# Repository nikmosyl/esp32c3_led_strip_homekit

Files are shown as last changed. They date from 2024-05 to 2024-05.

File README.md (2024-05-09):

# ESP32 LED Strip WS2812 HomeKit
[ru](https://github.com/nikmosyl/esp32c3_led_strip_homekit/blob/main/Readme/README-ru.md)

Hardware and Frimware for an addressable LED strip controller based on ESP32-C3

## Hardware

<kbd>
  
</kbd>

<kbd>
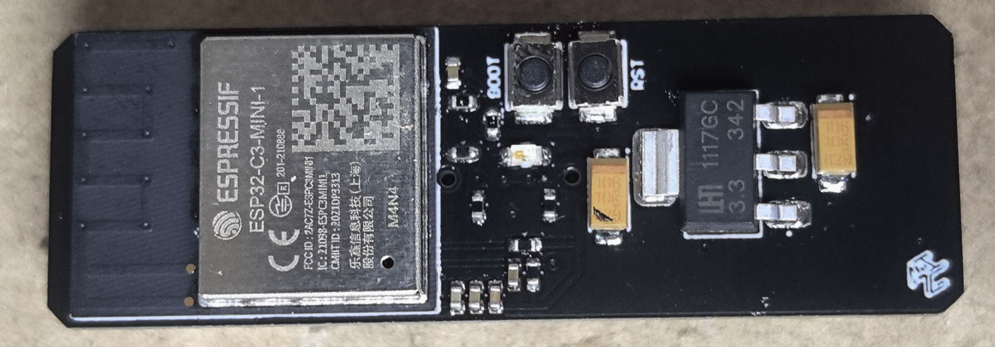
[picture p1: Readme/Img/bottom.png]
  
</kbd>

[altium 365 web preview](https://365.altium.com/files/029D88F9-241C-48A4-977B-14C8D9AD6741?variant=[No+Variations])

You can order it [here](https://www.pcbway.com/project/shareproject/ws2812esp32_3_v1_792a8e86.html)

On board:
- [Input connector](https://www.digikey.com/en/products/detail/amphenol-cs-commercial-products/FLTS22WR00/20422799) for power supply of the controller and LED strip (LED strip WS2812 or similar with +5V power supply)
- [Output connector](https://www.digikey.com/en/products/detail/amphenol-cs-commercial-products/FLTS32WR00/20426575) for power supply and control signal for addressable LED strip
- USB type C for programming ESP32-C3 controller

## Frimware
Based on Espressif [SDK](https://github.com/espressif/esp-homekit-sdk)

General installation steps using sources:

### 1. Install [ESP-IDF](https://docs.espressif.com/projects/esp-idf/en/stable/esp32c3/get-started/linux-macos-setup.html)
Preferred version v5.2.1

Preferred installation location is at the root of your home directory ~/

### 2. Install [esp-homekit-sdk](https://github.com/espressif/esp-homekit-sdk)
Preferred installation location is at the root of your home directory ~/

### 3. Download the repository with the project
```bash
cd ~/
git clone https://github.com/nikmosyl/esp32c3_led_strip_homekit.git
```

### 4. Configure HomeKit device and LED strip settings
File esp32c3_led_strip_homekit/frimware/lightbulb/main/app_main.c line 162:
```C
hap_acc_cfg_t cfg = {
    .name = "Esp-Light",                  //device name displayed in the Home app
    .manufacturer = "Espressif",          
    .model = "EspLight01",
    .serial_num = "202405030213",         //when using multiple devices, the number must be unique
    .fw_rev = "0.1.0",
    .hw_rev = "1.0",
    .pv = "1.1.0",
    .identify_routine = light_identify,
    .cid = HAP_CID_LIGHTING,
};
```
File frimware/lightbulb/main/Libs/internal_led/internal_led.c line 10:
```C
#define BLUE_LED 5    //GPIO number with debug LED on the board used
```
File frimware/lightbulb/main/Libs/led_strip/led_strip_control.c line 14:
```C
#define FLOW 30               //delay in milliseconds between switching on adjacent LEDs on the strip
#define LED_STRIP_GPIO 7      //GPIO number to which the DI pin of the LED strip is connected
#define LED_COUNT 10          //number of LEDs on LED strip
```

### 5. Set environment variables (can be skipped when installing idf and sdk in preferred paths)
You can either register temporary environment variables (specify the path to esp-homekit-sdk):
```bash
export HOMEKIT_PATH=~/esp/esp-homekit-sdk 
```
Or edit the file firmware/lightbulb/CMakeLists.txt line 11:
```CMake
set(HOMEKIT_PATH ~/esp/esp-homekit-sdk)
```
Instead of ~/esp/esp-homekit-sdk, specify your path to the esp-homekit-sdk directory

### 6. Set Wi-Fi password
You can either leave everything as it is, and then upon first launch, a QR code will be displayed in the console for connecting via [Espressif Provisioning Apps](https://docs.espressif.com/projects/esp-idf/en/latest/esp32/api-reference/provisioning/provisioning.html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) 

Or hardcode the Wi-Fi password into the controller:
```bash
cd ~/esp32c3_led_strip_homekit/frimware/lightbulb
. ~/esp/esp-idf/export.sh
```
Here the esp32c3 microcontroller to be flashed is selected as on the board from the Hardware section, you must specify the one that is on the board to be flashed
```bash
idf.py set-target esp32c3
idf.py menuconfig
```

In the section _**App Wi-Fi** -> **Source of Wi-Fi Credentials**_ you need to check the box for **Use Hardcoded**

In the fields that appear, you must enter the name and password of the access point

Press S (Save) and Enter after that

### 7. Flash the board
To do this, you need to connect the board to the PC, make sure that it is visible in the list of devices and there is access to its serial port;

Switch the board to firmware mode (on the board from the Hardware section this is done by pressing the RST button while holding down the BOOT button);

Build firmware:
```bash
idf.py build
```
Upload firmware to the board:
```bash
idf.py flash
```

### 8. After the firmware
Reboot the board
Wait until it connects to Wi-Fi and appears in the menu for adding new HomeKit devices (on iPhone, _**Home** app -> **+** -> **Other options** -> **select device**_ , code 11122333)

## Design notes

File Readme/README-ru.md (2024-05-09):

# ESP32 LED Strip WS2812 HomeKit
[en](https://github.com/nikmosyl/esp32c3_led_strip_homekit/blob/main/README.md)

Hardware и Frimware для контроллера адресной светодиодной ленты на базе ESP32-C3

## Hardware

<kbd>
  
</kbd>

<kbd>
  
</kbd>

[веб превью altium 365](https://365.altium.com/files/029D88F9-241C-48A4-977B-14C8D9AD6741?variant=[No+Variations])

Заказать можно [тут](https://www.pcbway.com/project/shareproject/ws2812esp32_3_v1_792a8e86.html)

На плате:
- [Входной разъём](https://www.digikey.com/en/products/detail/amphenol-cs-commercial-products/FLTS22WR00/20422799) для питание контролера и светодиодной ленты (светодиодная лента WS2812 или аналогичная с питанием +5V)
- [Выходной разъём](https://www.digikey.com/en/products/detail/amphenol-cs-commercial-products/FLTS32WR00/20426575) для питания и управляющего сигнала адресной светодиодной лентой
- USB type C для программирования контроллера ESP32-C3

## Frimware
Основано на [SDK](https://github.com/espressif/esp-homekit-sdk) от Espressif 

Общие шаги по установке c использованием исходников:

### 1. Установить [ESP-IDF](https://docs.espressif.com/projects/esp-idf/en/stable/esp32c3/get-started/linux-macos-setup.html)
Предпочительная версия v5.2.1

Предпочтительное место установки в корень домашней директории ~/

### 2. Установить [esp-homekit-sdk](https://github.com/espressif/esp-homekit-sdk)
Предпочтительное место установки в корень домашней директории ~/

### 3. Скачать репозиторий с проектом
```bash
cd ~/
git clone https://github.com/nikmosyl/esp32c3_led_strip_homekit.git
```

### 4. Настроить параметры HomeKit устройства и светодиодной ленты
Файл esp32c3_led_strip_homekit/frimware/lightbulb/main/app_main.c строка 162:
```C
hap_acc_cfg_t cfg = {
    .name = "Esp-Light",                  //отображаемое в приложении Дом название устройства
    .manufacturer = "Espressif",          
    .model = "EspLight01",
    .serial_num = "202405030213",         //при использовании нескольких устройств номер должен быть уникальным
    .fw_rev = "0.1.0",
    .hw_rev = "1.0",
    .pv = "1.1.0",
    .identify_routine = light_identify,
    .cid = HAP_CID_LIGHTING,
};
```
Файл frimware/lightbulb/main/Libs/internal_led/internal_led.c строка 10:
```C
#define BLUE_LED 5    //номер GPIO с отладочным свтодиодом на используемой плате
```
Файл frimware/lightbulb/main/Libs/led_strip/led_strip_control.c строка 14:
```C
#define FLOW 30               //задержка в милесекундах между включениями соседних сетодиодов на ленте
#define LED_STRIP_GPIO 7      //номер GPIO к которому подлючен контакт DI светодиодной ленты
#define LED_COUNT 10          //количество светодиодов на светодиодной ленте
```

### 5. Прописать переменные окружения (можно пропустить при установке idf и sdk по предпочтительным путям)
Можно либо прописать временные переменные окружения (указать путь до esp-homekit-sdk):
```bash
export HOMEKIT_PATH=~/esp/esp-homekit-sdk 
```
Либо отредоктировать файл frimware/lightbulb/CMakeLists.txt строка 11:
```CMake
set(HOMEKIT_PATH ~/esp/esp-homekit-sdk)
```
вместо ~/esp/esp-homekit-sdk указать свой путь к каталогу esp-homekit-sdk

### 6. Установить пароль Wi-Fi
Можно либо оставить всё как есть и тогда при первом запуске в консоль выведется QR код для подключения через [Espressif Provisioning Apps](https://docs.espressif.com/projects/esp-idf/en/latest/esp32/api-reference/provisioning/provisioning.html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) 

Либо зашить пароль от Wi-Fi в контроллер жёстко:
```bash
cd ~/esp32c3_led_strip_homekit/frimware/lightbulb
. ~/esp/esp-idf/export.sh
```
Здесь выбран прошиваемый микроконтроллер esp32c3 как на плате из раздела Hardware, необходимо указать тот, который стоит на прошиваемой плате
```bash
idf.py set-target esp32c3
idf.py menuconfig
```

В разделе _**App Wi-Fi** -> **Source of Wi-Fi Credentials**_ нужно установить галочку на **Use Hardcoded**

В появившиеся поля необходимо ввести имя и пароль точки доступа

Нажать S (Save) и Enter после этого

### 7. Прошить плату
Для этого нужно подключить плату к ПК, убедиться, что она видна в списке устройств и к её последовательному порту есть доступ;

Перевести плату в режим прошивки (на плате из раздела Hardware это делается путём нажатия кнопки RST при удерживании кнопки BOOT);

Собрать прошивку:
```bash
idf.py build
```
Загрузить прошивку на плату:
```bash
idf.py flash
```

### 8. После прошивки
Перезагрузить плату
Дождаться пока она подключится к Wi-Fi и отобразится в меню добавления новых устройств HomeKit (на iPhone приложение _**Дом** -> **+** -> **Другие параметры** -> **выберете устройство**_, код 11122333)

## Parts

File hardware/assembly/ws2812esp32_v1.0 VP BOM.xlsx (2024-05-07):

Designator | Quantity | Manufacture | Part Number | Description | Case | Case Type
C1, C2, C10 | 3 | Murata | GRM155R71H104KE14D | CAP CER 0.1UF 50V X7R 0402 | 0402 | SMD
C3, C7 | 2 | Kemet | T491A106K010AT | CAP TANT 10UF 10% 10V 1206 | Molded A | SMD
C4, C6 | 2 | Murata | GRM1555C1H150JA01D | CAP CER 15PF 50V C0G/NP0 0402 | 0402 | SMD
C5, C8, C11 | 3 | Murata | GRM155R61E105KA12D | CAP CER 1UF 25V X5R 0402 | 0402 | SMD
C9 | 1 | Murata | GRM155R71E103KA01D | CAP CER 10000PF 25V X7R 0402 | 0402 | SMD
DA1 | 1 | Taejin | LM1117GS-3.3 | IC REG LINEAR 3.3V 1A SOT223-3 | SOT-223 | SMD
DD1 | 1 | TI | SN74LVC1T45DCK | IC TRANSLTR BIDIRECTIONAL SC70-6 | SC70 DCK | SMD
DD2 | 1 | Espressif | ESP32-C3-MINI-1 | RF TXRX MODULE BT PCB TRACE SMD | SMD Module 13.2 x 12.5 x 2.4 | SMD
HL1 | 1 | Kingbright | APT1608QBC/D | LED 0603 Blue | 0603 | SMD
K1, K2 | 2 | Omron | B3U-1000P-B | SWITCH TACTILE SPST-NO 0.05A 12V | 3.0 x 2.5 x 1.85 | SMD
R1, R2, R7, R8 | 4 | Yageo | RC0402FR-0710KL | RES 10K OHM 1/16W 1% 0402 SMD | 0402 | SMD
R3, R4 | 2 | Yageo | RC0402FR-075K1L | RES 5.1K OHM 1/16W 1% 0402 SMD | 0402 | SMD
R5, R6 | 2 | Yageo | RC0402FR-0722RL | RES 22 OHM 1/16W 1% 0402 SMD | 0402 | SMD
R9 | 1 | Yageo | RC0402FR-071KL | RES 1K OHM 1/16W 1% 0402 SMD | 0402 | SMD
VD1 | 1 | MDD | DSK14 | DIODE SCHOTTKY 40V 1A | SOD-123FL | SMD
XS1 | 1 | Amphenol | FLTS22WR00 | SMD TERMINAL BLOCK 2 PIN | 7.9 x 13.1 x 4.6 | SMD
XS2 | 1 | GCT | USB4110-GF-A | CONN RCP USB2.0 TYP C 24P SMD RA | USB2.0 TYP C 24P SMD RA | SMD
XS3 | 1 | Amphenol | FLTS32WR00 | SMD TERMINAL BLOCK 3 PIN | 11.9 x 13.1 x 4.6 | SMD

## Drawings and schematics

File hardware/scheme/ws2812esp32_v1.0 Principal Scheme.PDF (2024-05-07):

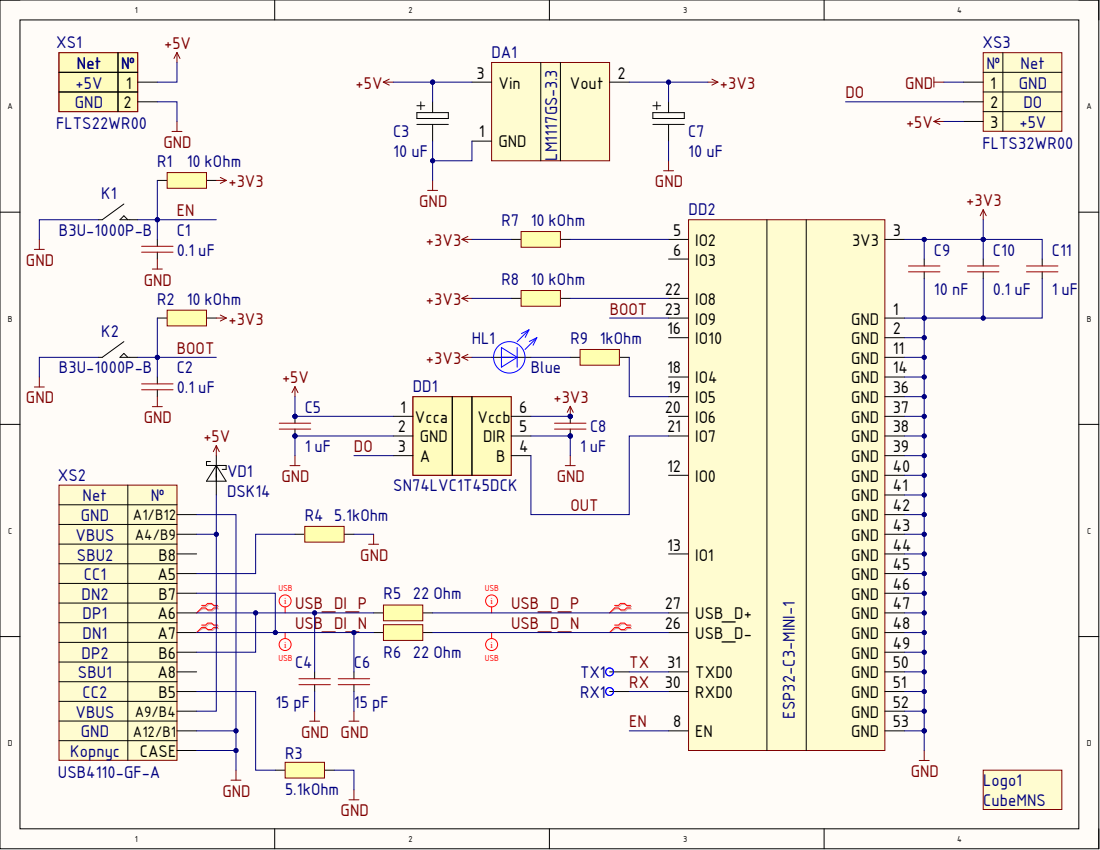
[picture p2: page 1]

Net | №
GND | A1/B12
VBUS | A4/B9
SBU2 | B8
CC1 | A5
DN2 | B7
DP1 | A6
DN1 | A7
DP2 | B6
SBU1 | A8
CC2 | B5
VBUS | A9/B4
GND | A12/B1
Корпус | CASE

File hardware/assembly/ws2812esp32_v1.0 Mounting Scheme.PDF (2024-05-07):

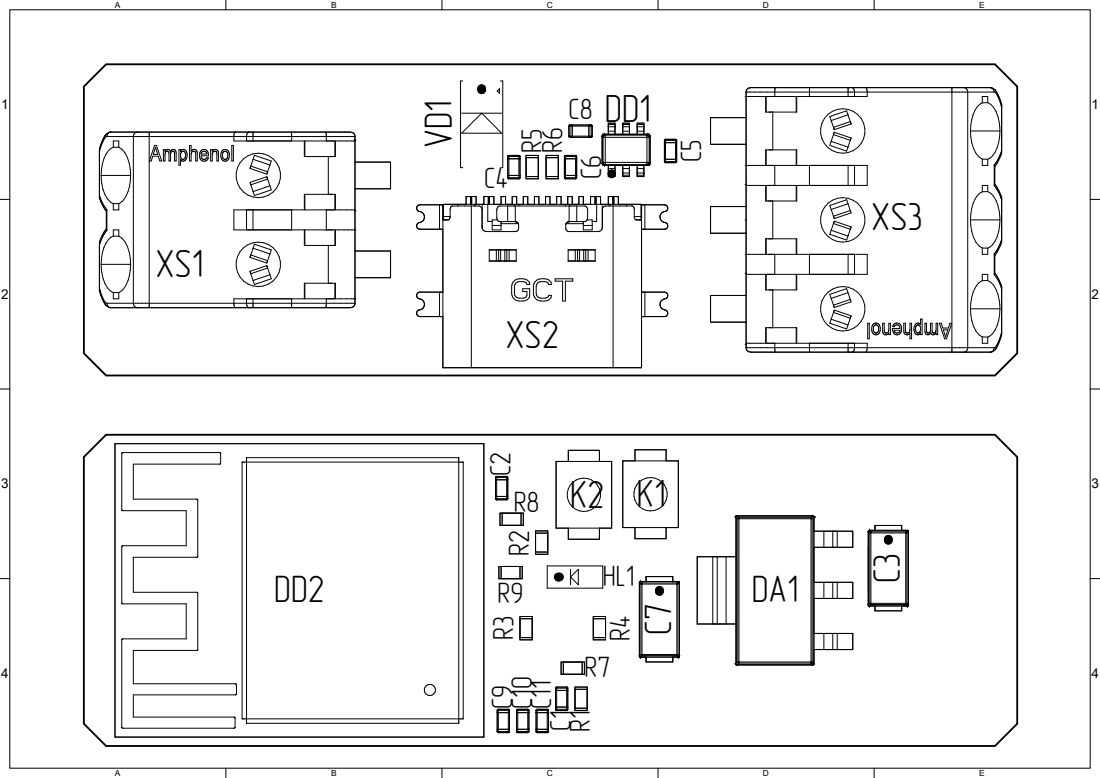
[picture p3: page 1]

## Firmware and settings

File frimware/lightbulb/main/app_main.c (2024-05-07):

/*
 * ESPRESSIF MIT License
 *
 * Copyright (c) 2018 <ESPRESSIF SYSTEMS (SHANGHAI) PTE LTD>
 *
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
 */

/* HomeKit Lightbulb for esp32c3 custom board
*/

#include <stdio.h>
#include <string.h>
#include <freertos/FreeRTOS.h>
#include <freertos/task.h>
#include <esp_log.h>

#include <hap.h>
#include <hap_apple_servs.h>
#include <hap_apple_chars.h>
#include <hap_fw_upgrade.h>

#include <iot_button.h>

#include <app_wifi.h>
#include <app_hap_setup_payload.h>

#include "lightbulb.h"

#include "Libs/internal_led/internal_led.h"

/* Comment out the below line to disable Firmware Upgrades */
#define CONFIG_FIRMWARE_SERVICE

static const char *TAG = "HAP lightbulb";

#define LIGHTBULB_TASK_PRIORITY  1
#define LIGHTBULB_TASK_STACKSIZE 4 * 1024
#define LIGHTBULB_TASK_NAME      "hap_lightbulb"

/* Reset network credentials if button is pressed for more than 3 seconds and then released */
#define RESET_NETWORK_BUTTON_TIMEOUT        3

/* Reset to factory if button is pressed and held for more than 10 seconds */
#define RESET_TO_FACTORY_BUTTON_TIMEOUT     10

/* The button "Boot" will be used as the Reset button for the example */
#define RESET_GPIO  GPIO_NUM_9
/**
 * @brief The network reset button callback handler.
 * Useful for testing the Wi-Fi re-configuration feature of WAC2
 */

static void reset_network_handler(void* arg)
{
    hap_reset_network();
}
/**
 * @brief The factory reset button callback handler.
 */
static void reset_to_factory_handler(void* arg)
{
    hap_reset_to_factory();
}

/**
 * The Reset button  GPIO initialisation function.
 * Same button will be used for resetting Wi-Fi network as well as for reset to factory based on
 * the time for which the button is pressed.
 */
static void reset_key_init(uint32_t key_gpio_pin)
{
    button_handle_t handle = iot_button_create(key_gpio_pin, BUTTON_ACTIVE_LOW);
    iot_button_add_on_release_cb(handle, RESET_NETWORK_BUTTON_TIMEOUT, reset_network_handler, NULL);
    iot_button_add_on_press_cb(handle, RESET_TO_FACTORY_BUTTON_TIMEOUT, reset_to_factory_handler, NULL);
}

/* Mandatory identify routine for the accessory.
 * In a real accessory, something like LED blink should be implemented
 * got visual identification
 */
static int light_identify(hap_acc_t *ha)
{
    ESP_LOGI(TAG, "Accessory identified");
    return HAP_SUCCESS;
}

/* Callback for handling writes on the Light Bulb Service
 */
static int lightbulb_write(hap_write_data_t write_data[], int count,
        void *serv_priv, void *write_priv)
{
    int i, ret = HAP_SUCCESS;
    hap_write_data_t *write;
    for (i = 0; i < count; i++) {
        write = &write_data[i];
        /* Setting a default error value */
        *(write->status) = HAP_STATUS_VAL_INVALID;
        if (!strcmp(hap_char_get_type_uuid(write->hc), HAP_CHAR_UUID_ON)) {
            ESP_LOGI(TAG, "Received Write for Light %s", write->val.b ? "On" : "Off");
            if (lightbulb_set_on(write->val.b) == 0) {
                *(write->status) = HAP_STATUS_SUCCESS;
            }
        } else if (!strcmp(hap_char_get_type_uuid(write->hc), HAP_CHAR_UUID_BRIGHTNESS)) {
            ESP_LOGI(TAG, "Received Write for Light Brightness %d", write->val.i);
            if (lightbulb_set_brightness(write->val.i) == 0) {
                *(write->status) = HAP_STATUS_SUCCESS;
            }
        } else if (!strcmp(hap_char_get_type_uuid(write->hc), HAP_CHAR_UUID_HUE)) {
            ESP_LOGI(TAG, "Received Write for Light Hue %f", write->val.f);
            if (lightbulb_set_hue(write->val.f) == 0) {
                *(write->status) = HAP_STATUS_SUCCESS;
            }
        } else if (!strcmp(hap_char_get_type_uuid(write->hc), HAP_CHAR_UUID_SATURATION)) {
            ESP_LOGI(TAG, "Received Write for Light Saturation %f", write->val.f);
            if (lightbulb_set_saturation(write->val.f) == 0) {
                *(write->status) = HAP_STATUS_SUCCESS;
            }
        } else {
            *(write->status) = HAP_STATUS_RES_ABSENT;
        }
        /* If the characteristic write was successful, update it in hap core
         */
        if (*(write->status) == HAP_STATUS_SUCCESS) {
            hap_char_update_val(write->hc, &(write->val));
        } else {
            /* Else, set the return value appropriately to report error */
            ret = HAP_FAIL;
        }
    }
    return ret;
}

/*The main thread for handling the Light Bulb Accessory */
static void lightbulb_thread_entry(void *arg)
{
    hap_acc_t *accessory;
    hap_serv_t *service;

    /* Initialize the HAP core */
    hap_init(HAP_TRANSPORT_WIFI);

    /* Initialise the mandatory parameters for Accessory which will be added as
     * the mandatory services internally
     */
    hap_acc_cfg_t cfg = {
        .name = "Esp-Light",
        .manufacturer = "Espressif",
        .model = "EspLight01",
        .serial_num = "202405030213",
        .fw_rev = "0.1.0",
        .hw_rev = "1.0",
        .pv = "1.1.0",
        .identify_routine = light_identify,
        .cid = HAP_CID_LIGHTING,
    };

    /* Create accessory object */
    accessory = hap_acc_create(&cfg);
    if (!accessory) {
        ESP_LOGE(TAG, "Failed to create accessory");
        goto light_err;
    }

    /* Add a dummy Product Data */
    uint8_t product_data[] = {'E','S','P','3','2','H','A','P'};
    hap_acc_add_product_data(accessory, product_data, sizeof(product_data));

    /* Add Wi-Fi Transport service required for HAP Spec R16 */
    hap_acc_add_wifi_transport_service(accessory, 0);

    /* Create the Light Bulb Service. Include the "name" since this is a user visible service  */
    service = hap_serv_lightbulb_create(false);
    if (!service) {
        ESP_LOGE(TAG, "Failed to create LightBulb Service");
        goto light_err;
    }

    /* Add the optional characteristic to the Light Bulb Service */
    int ret = hap_serv_add_char(service, hap_char_name_create("My Light"));
    ret |= hap_serv_add_char(service, hap_char_brightness_create(10));
    ret |= hap_serv_add_char(service, hap_char_hue_create(30));
    ret |= hap_serv_add_char(service, hap_char_saturation_create(90));
    
    if (ret != HAP_SUCCESS) {
        ESP_LOGE(TAG, "Failed to add optional characteristics to LightBulb");
        goto light_err;
    }
    /* Set the write callback for the service */
    hap_serv_set_write_cb(service, lightbulb_write);
    
    /* Add the Light Bulb Service to the Accessory Object */
    hap_acc_add_serv(accessory, service);


    //DROP ?
#ifdef CONFIG_FIRMWARE_SERVICE
    /*  Required for server verification during OTA, PEM format as string  */
    static char server_cert[] = {};
    hap_fw_upgrade_config_t ota_config = {
        .server_cert_pem = server_cert,
    };
    /* Create and add the Firmware Upgrade Service, if enabled.
     * Please refer the FW Upgrade documentation under components/homekit/extras/include/hap_fw_upgrade.h
     * and the top level README for more information.
     */
    service = hap_serv_fw_upgrade_create(&ota_config);
    if (!service) {
        ESP_LOGE(TAG, "Failed to create Firmware Upgrade Service");
        goto light_err;
    }
    hap_acc_add_serv(accessory, service);
#endif
    //DROP ?

    /* Add the Accessory to the HomeKit Database */
    hap_add_accessory(accessory);

    /* Initialize the Light Bulb Hardware */
    lightbulb_init();

    /* Register a common button for reset Wi-Fi network and reset to factory.
     */
    reset_key_init(RESET_GPIO);

    /* TODO: Do the actual hardware initialization here */

    /* For production accessories, the setup code shouldn't be programmed on to
     * the device. Instead, the setup info, derived from the setup code must
     * be used. Use the factory_nvs_gen utility to generate this data and then
     * flash it into the factory NVS partition.
     *
     * By default, the setup ID and setup info will be read from the factory_nvs
     * Flash partition and so, is not required to set here explicitly.
     *
     * However, for testing purpose, this can be overridden by using hap_set_setup_code()
     * and hap_set_setup_id() APIs, as has been done here.
     */
#ifdef CONFIG_EXAMPLE_USE_HARDCODED_SETUP_CODE
    /* Unique Setup code of the format xxx-xx-xxx. Default: 111-22-333 */
    hap_set_setup_code(CONFIG_EXAMPLE_SETUP_CODE);
    /* Unique four character Setup Id. Default: ES32 */
    hap_set_setup_id(CONFIG_EXAMPLE_SETUP_ID);
#ifdef CONFIG_APP_WIFI_USE_WAC_PROVISIONING
    app_hap_setup_payload(CONFIG_EXAMPLE_SETUP_CODE, CONFIG_EXAMPLE_SETUP_ID, true, cfg.cid);
#else
    app_hap_setup_payload(CONFIG_EXAMPLE_SETUP_CODE, CONFIG_EXAMPLE_SETUP_ID, false, cfg.cid);
#endif
#endif

    /* Enable Hardware MFi authentication (applicable only for MFi variant of SDK) */
    hap_enable_mfi_auth(HAP_MFI_AUTH_HW);

    /* Initialize Wi-Fi */
    app_wifi_init();

    /* After all the initializations are done, start the HAP core */
    hap_start();
    /* Start Wi-Fi */
    app_wifi_start(portMAX_DELAY);

    /* The task ends here. The read/write callbacks will be invoked by the HAP Framework */
    vTaskDelete(NULL);

light_err:
    hap_acc_delete(accessory);
    vTaskDelete(NULL);
}

void app_main()
{
    internal_led_on();

    xTaskCreate(lightbulb_thread_entry, LIGHTBULB_TASK_NAME, LIGHTBULB_TASK_STACKSIZE,
            NULL, LIGHTBULB_TASK_PRIORITY, NULL);
}

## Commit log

2024-05-02 initial file placement
    [Pick Place for ws2812esp32_v1.0.csv, partitions_hap.csv, ws2812esp32_v1.0 VP BOM.xlsx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]
2024-05-02 assembly procedure changed
2024-05-03 Implemented control of addressable LED strip
2024-05-07 Update led_strip_control.c for usb port safety
